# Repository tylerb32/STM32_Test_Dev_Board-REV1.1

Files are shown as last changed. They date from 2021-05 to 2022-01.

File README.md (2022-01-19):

# STM32_Test_Dev_Board-REV1.1
*Currently a work in progress<br/>
The purpose of this project is to gain experience with embedded system design, electronics and PCB design, and firmware/real-time software development in FreeRTOS.<br/>
Status: PCBs assembled (Investigating accelerometer hardware implementation).

Changes from REV 1:
- Changed component selection for MCU, crystal oscillator, and accelerometer due to availability and cost constraints
- Added switches for user input
- Improved positioning of LCD headers and ensured the screen won't block any other headers or connectors when plugged in
- Changed micro USB footprint
- Routed CBUS pins from UART-USB bridge and interrupt pins from the accelerometer to the MCU instead of external headers
- Routed remaining pins including LPUART to external headers

PCB 3D View
PCB Routing

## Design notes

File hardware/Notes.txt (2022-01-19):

Possible Improvements for Next Revision:
- Power LED
	- Nice to see if board is getting powered
- Test points
- Don't underestimate flash memory requirements

Testing:
	- Shuts off after 18 seconds when plugged into usb power pack
		* Does not occur when plugged into computer
		- Could be a result of USB suspend mode?
		- May need to program ftdi chip for usb charger use

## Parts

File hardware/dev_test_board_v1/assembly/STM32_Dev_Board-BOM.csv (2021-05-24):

Comment | Designator | Footprint | LCSC
10n | C1 | Capacitor_SMD:C_0603_1608Metric | C57112
1u | C11 | Capacitor_SMD:C_0402_1005Metric | C52923
6p | C13,C14 | Capacitor_SMD:C_0402_1005Metric | C30274
10u | C7,C15 | Capacitor_SMD:C_0402_1005Metric | C15525
4.7u | C2 | Capacitor_SMD:CP_Elec_4x5.4
100n | C3,C4,C8,C9,C10,C12,C16,C17 | Capacitor_SMD:C_0402_1005Metric | C1525
47p | C5,C6 | Capacitor_SMD:C_0603_1608Metric | C1671
YELLOW | D2 | LED_SMD:LED_0603_1608Metric | C72038
GREEN | D3 | LED_SMD:LED_0603_1608Metric | C72043
RED | D4 | LED_SMD:LED_0603_1608Metric | C2286
BLUE | D5 | LED_SMD:LED_0603_1608Metric | C72041
600R @ 100MHz | FB1 | Inductor_SMD:L_0805_2012Metric | C1017
MountingHole_Pad | H1,H2,H3,H4 | MountingHole:MountingHole_2.7mm_M2.5_Pad_Via
USB_B_Micro | J1 | tyjba_footprints:UBS_Micro-B_Citzends_Aliexpress
Conn_SWD | J2 | Connector_PinHeader_1.27mm:PinHeader_2x05_P1.27mm_Vertical
Conn_LCD | J3 | Connector_PinSocket_2.54mm:PinSocket_1x08_P2.54mm_Vertical
Conn_GP | J4 | Connector_PinHeader_2.54mm:PinHeader_1x12_P2.54mm_Vertical
27n | L1 | Inductor_SMD:L_0603_1608Metric | C12100
22R | R10 | Resistor_SMD:R_0402_1005Metric | C25092
1k | R11,R12,R13 | Resistor_SMD:R_0402_1005Metric | C11702
27R | R1,R2 | Resistor_SMD:R_0603_1608Metric | C25190
270R | R3,R4 | Resistor_SMD:R_0603_1608Metric | C22966
10k | R5 | Resistor_SMD:R_0402_1005Metric | C25744
1k | R6,R7 | Resistor_SMD:R_0603_1608Metric | C21190
4R7 | R8,R9 | Resistor_SMD:R_0402_1005Metric | C25900
SW_SPDT | SW1 | tyjba_footprints:SW_Unknown_SPDT_Straight
SW_PUSH | SW2,SW3,SW4 | Button_Switch_SMD:SW_Push_1P1T_NO_6x6mm_H9.5mm
STM32L031C4Tx | U1 | Package_QFP:LQFP-48_7x7mm_P0.5mm
FT230XS | U2 | Package_SO:SSOP-16_3.9x4.9mm_P0.635mm
LIS2HH12 | U3 | Package_LGA:LGA-12_2x2mm_P0.5mm
8MHz | Y1 | tyjba_footprints:Crystal_NX8045GB

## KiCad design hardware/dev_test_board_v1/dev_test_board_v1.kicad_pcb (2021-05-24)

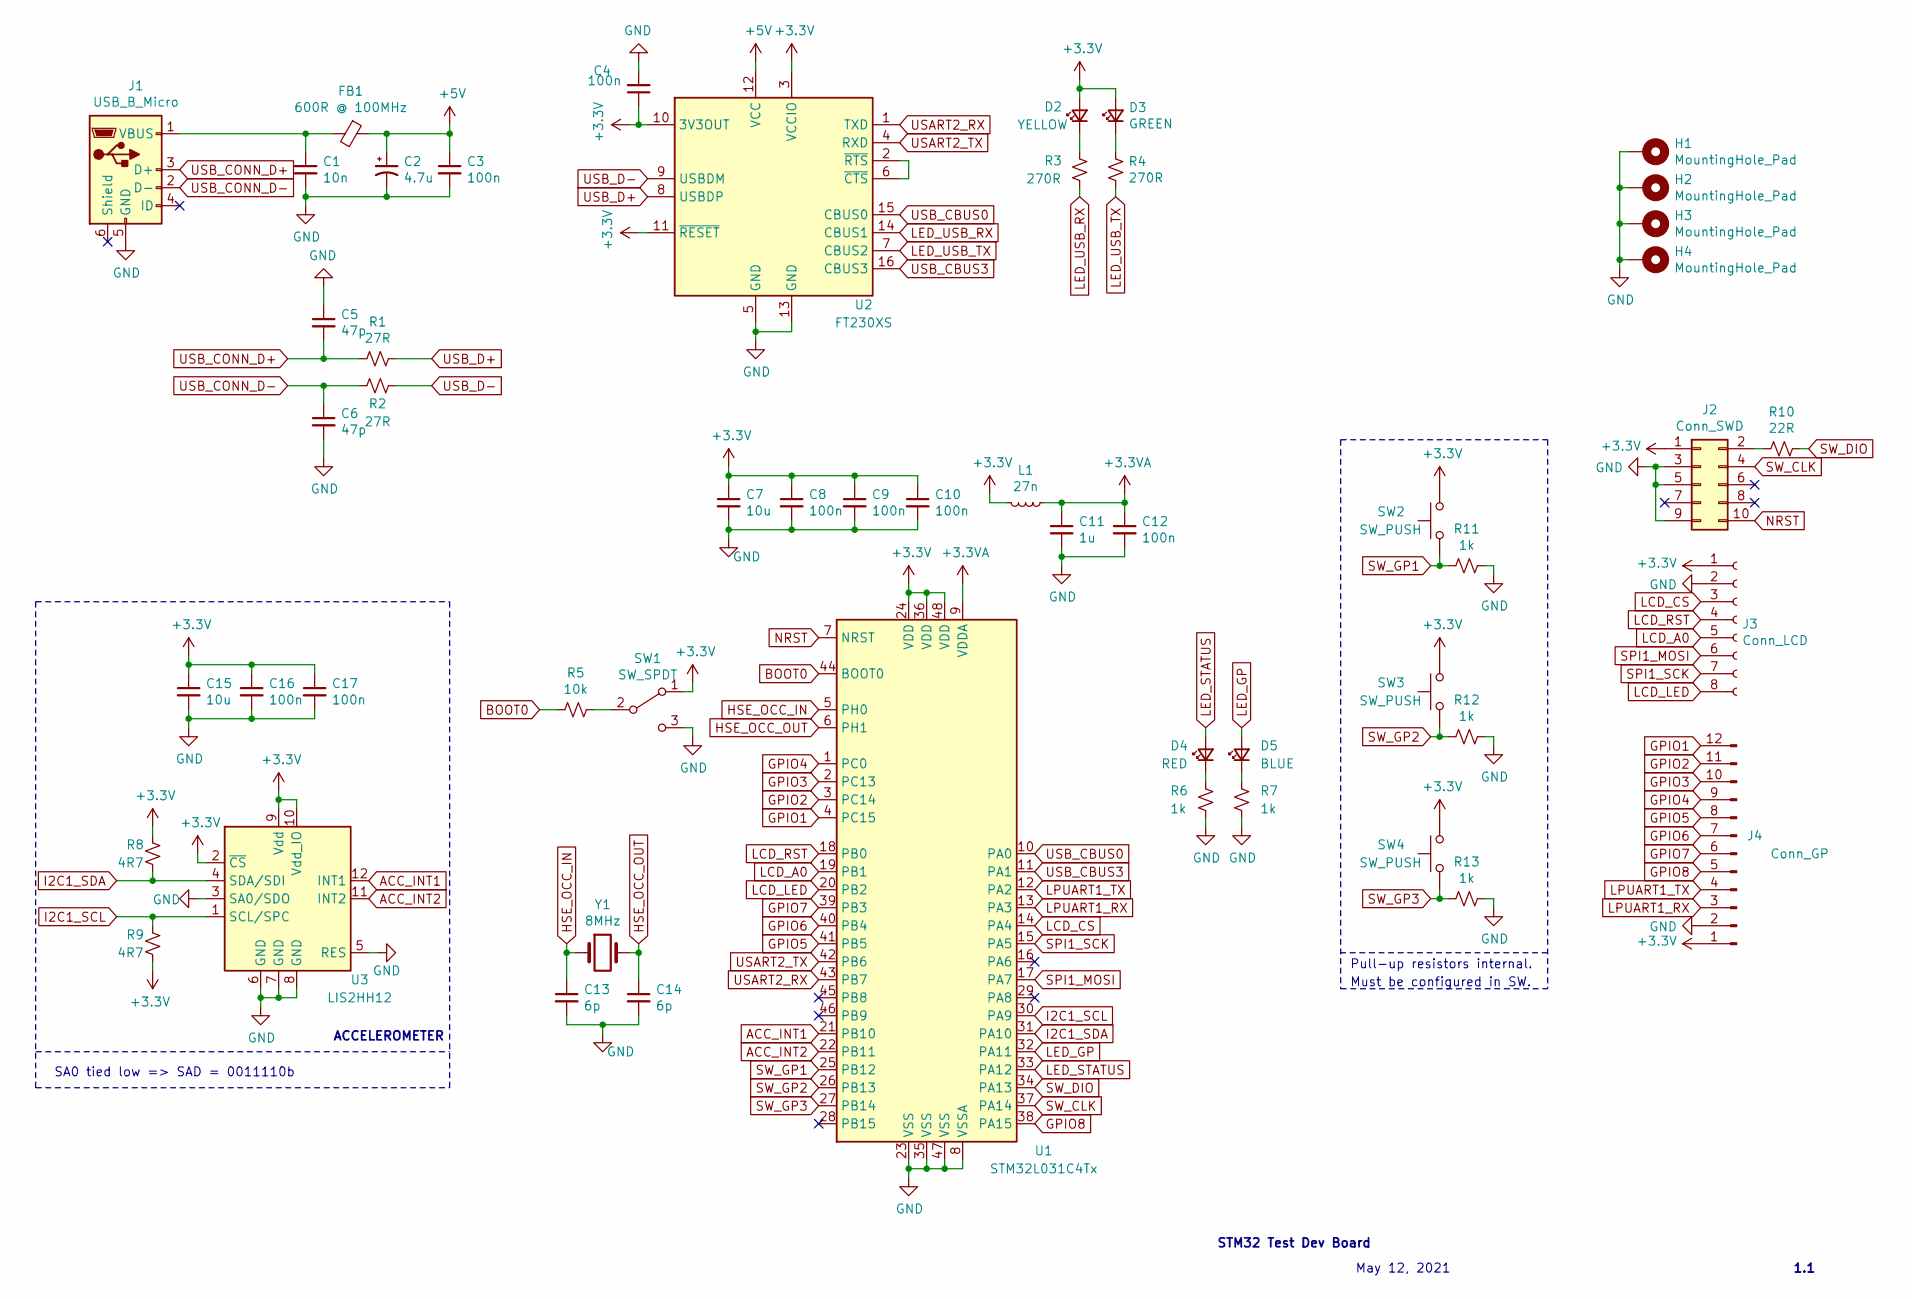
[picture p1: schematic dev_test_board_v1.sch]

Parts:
C1: 10n; C_0603_1608Metric; LCSC Part # C57112
C2: 4.7u; CP_Elec_4x5.4
C3, C4, C8, C9, C10, C12, C16, C17: 100n; C_0402_1005Metric; LCSC Part # C1525
C5, C6: 47p; C_0603_1608Metric; LCSC Part # C1671
C7, C15: 10u; C_0402_1005Metric; LCSC Part # C15525
C11: 1u; C_0402_1005Metric; LCSC Part # C52923
C13, C14: 6p; C_0402_1005Metric; LCSC Part # C30274
D2: YELLOW; LED_0603_1608Metric; LCSC Part # C72038
D3: GREEN; LED_0603_1608Metric; LCSC Part # C72043
D4: RED; LED_0603_1608Metric; LCSC Part # C2286
D5: BLUE; LED_0603_1608Metric; LCSC Part # C72041
FB1: 600R @ 100MHz; L_0805_2012Metric; LCSC Part # C1017
H1, H2, H3, H4: MountingHole_Pad; MountingHole_2.7mm_M2.5_Pad_Via
J1: USB_B_Micro; UBS_Micro-B_Citzends_Aliexpress
J2: Conn_SWD; PinHeader_2x05_P1.27mm_Vertical
J3: Conn_LCD; PinSocket_1x08_P2.54mm_Vertical
J4: Conn_GP; PinHeader_1x12_P2.54mm_Vertical
L1: 27n; L_0603_1608Metric; LCSC Part # C12100
R1, R2: 27R; R_0603_1608Metric; LCSC Part # C25190
R3, R4: 270R; R_0603_1608Metric; LCSC Part # C22966
R5: 10k; R_0402_1005Metric; LCSC Part # C25744
R6, R7: 1k; R_0603_1608Metric; LCSC Part # C21190
R8, R9: 4R7; R_0402_1005Metric; LCSC Part # C25900
R10: 22R; R_0402_1005Metric; LCSC Part # C25092
R11, R12, R13: 1k; R_0402_1005Metric; LCSC Part # C11702
SW1: SW_SPDT; SW_Unknown_SPDT_Straight
SW2, SW3, SW4: SW_PUSH; SW_Push_1P1T_NO_6x6mm_H9.5mm
U1: STM32L031C4Tx; LQFP-48_7x7mm_P0.5mm
U2: FT230XS; SSOP-16_3.9x4.9mm_P0.635mm
U3: LIS2HH12; LGA-12_2x2mm_P0.5mm
Y1: 8MHz; Crystal_NX8045GB

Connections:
+3.3VA: C11.1, C12.1, L1.1, U1.9 (VDDA)
+3V3: C4.1, C7.1, C8.1, C9.1, C10.1, C15.1, C16.1, C17.1, D2.2 (A), D3.2 (A), J2.1, J3.1, J4.1, L1.2, R8.2, R9.1, SW1.1 (A), SW2.2, SW3.2, SW4.2, U1.24 (VDD), U1.36 (VDD), U1.48 (VDD), U2.3 (VCCIO), U2.10 (3V3OUT), U2.11 (~RESET), U3.2 (~CS), U3.9 (Vdd), U3.10 (Vdd_IO)
+5V: C2.1, C3.1, FB1.1, U2.12 (VCC)
ACC_INT1: U1.21 (PB10), U3.12 (INT1)
ACC_INT2: U1.22 (PB11), U3.11 (INT2)
BOOT0: R5.2, U1.44 (BOOT0)
GND: C1.2, C2.2, C3.2, C4.2, C5.1, C6.2, C7.2, C8.2, C9.2, C10.2, C11.2, C12.2, C13.2, C14.2, C15.2, C16.2, C17.2, H1.1, H2.1, H3.1, H4.1, J1.5 (GND), J2.3, J2.5, J2.9, J3.2, J4.2, R6.2, R7.2, R11.1, R12.1, R13.1, SW1.3 (C), U1.8 (VSSA), U1.23 (VSS), U1.35 (VSS), U1.47 (VSS), U2.5 (GND), U2.13 (GND), U3.3 (SA0/SDO), U3.5 (RES), U3.6 (GND), U3.7 (GND), U3.8 (GND)
GPIO1: J4.12, U1.4 (PC15)
GPIO2: J4.11, U1.3 (PC14)
GPIO3: J4.10, U1.2 (PC13)
GPIO4: J4.9, U1.1 (PC0)
GPIO5: J4.8, U1.41 (PB5)
GPIO6: J4.7, U1.40 (PB4)
GPIO7: J4.6, U1.39 (PB3)
GPIO8: J4.5, U1.38 (PA15)
HSE_OCC_IN: C13.1, U1.5 (PH0), Y1.1
HSE_OCC_OUT: C14.1, U1.6 (PH1), Y1.2
I2C1_SCL: R9.2, U1.30 (PA9), U3.1 (SCL/SPC)
I2C1_SDA: R8.1, U1.31 (PA10), U3.4 (SDA/SDI)
LCD_A0: J3.5, U1.19 (PB1)
LCD_CS: J3.3, U1.14 (PA4)
LCD_LED: J3.8, U1.20 (PB2)
LCD_RST: J3.4, U1.18 (PB0)
LED_GP: D5.2 (A), U1.32 (PA11)
LED_STATUS: D4.2 (A), U1.33 (PA12)
LED_USB_RX: R3.2, U2.14 (CBUS1)
LED_USB_TX: R4.2, U2.7 (CBUS2)
LPUART1_RX: J4.3, U1.13 (PA3)
LPUART1_TX: J4.4, U1.12 (PA2)
NRST: J2.10, U1.7 (NRST)
unnamed: C1.1, FB1.2, J1.1 (VBUS)
unnamed: D2.1 (K), R3.1
unnamed: D3.1 (K), R4.1
unnamed: D4.1 (K), R6.1
unnamed: D5.1 (K), R7.1
unnamed: J2.2, R10.2
unnamed: R5.1, SW1.2 (B)
unnamed: U2.2 (~RTS), U2.6 (~CTS)
SPI1_MOSI: J3.6, U1.17 (PA7)
SPI1_SCK: J3.7, U1.15 (PA5)
SW_CLK: J2.4, U1.37 (PA14)
SW_DIO: R10.1, U1.34 (PA13)
SW_GP1: R11.2, SW2.1, U1.25 (PB12)
SW_GP2: R12.2, SW3.1, U1.26 (PB13)
SW_GP3: R13.2, SW4.1, U1.27 (PB14)
USART2_RX: U1.43 (PB7), U2.1 (TXD)
USART2_TX: U1.42 (PB6), U2.4 (RXD)
USB_CBUS0: U1.10 (PA0), U2.15 (CBUS0)
USB_CBUS3: U1.11 (PA1), U2.16 (CBUS3)
USB_CONN_D+: C5.2, J1.3 (D+), R1.2
USB_CONN_D-: C6.1, J1.2 (D-), R2.2
USB_D+: R1.1, U2.8 (USBDP)
USB_D-: R2.1, U2.9 (USBDM)

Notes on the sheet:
May 12, 2021
STM32 Test Dev Board
1.1
SA0 tied low => SAD = 0011110b
ACCELEROMETER
Pull-up resistors internal.
Must be configured in SW.

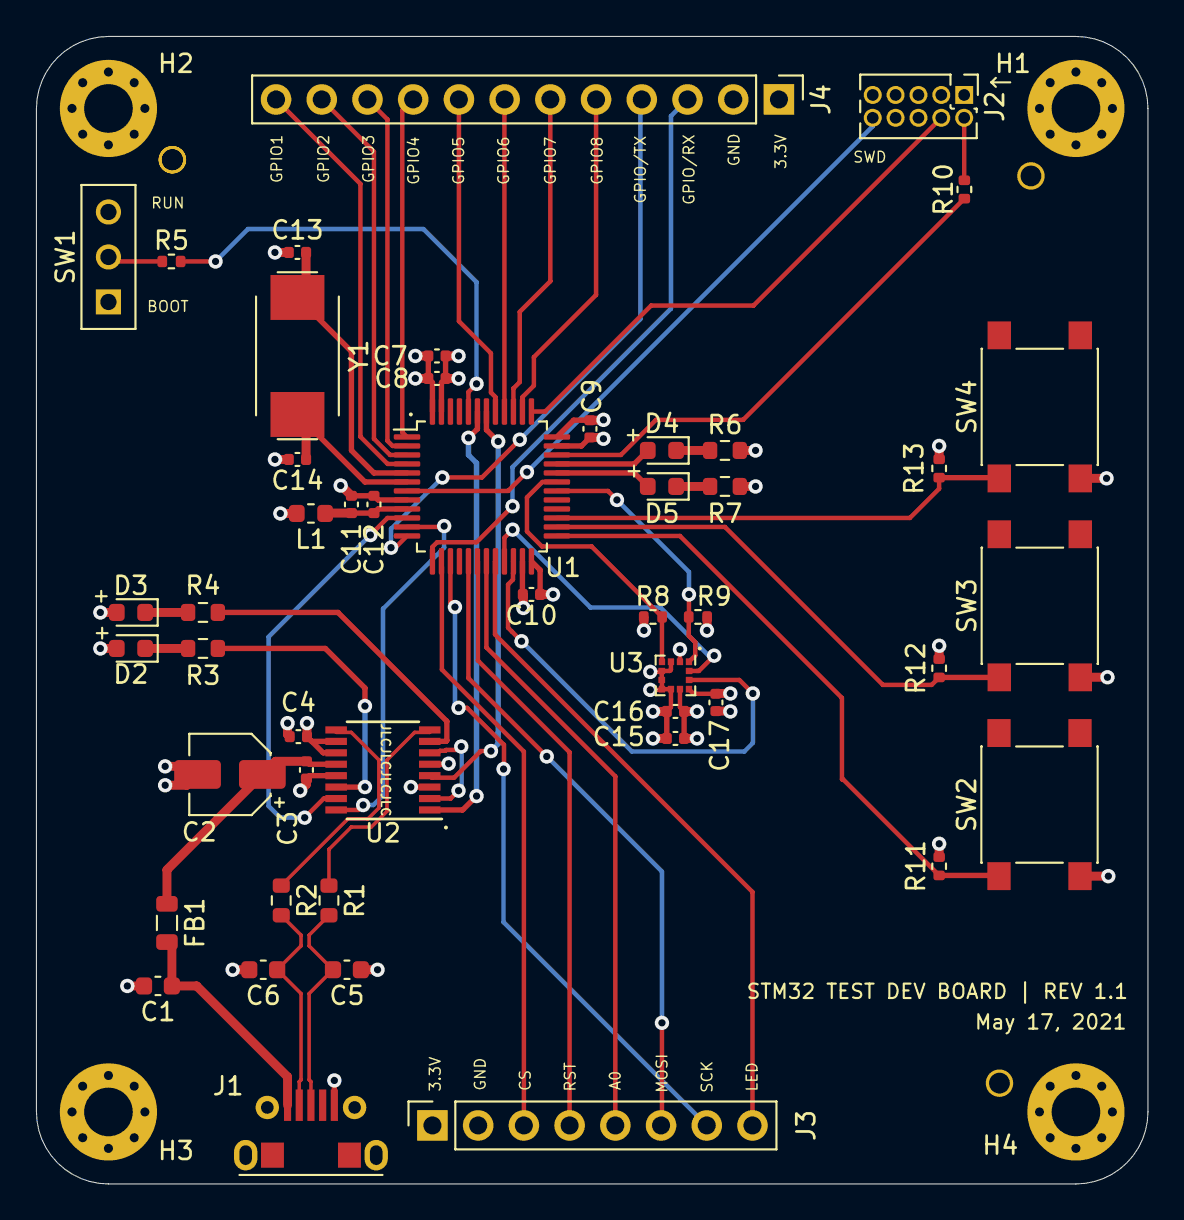
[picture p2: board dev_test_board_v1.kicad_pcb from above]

Board: 4 copper layers, 61.8 x 63.8 mm, 52 parts (0 on the bottom side), 53 nets.

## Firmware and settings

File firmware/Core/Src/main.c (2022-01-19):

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
/* Includes ------------------------------------------------------------------*/
#include "main.h"

/* USER CODE BEGIN Includes */
#include "LIS2HH12.h"
/* USER CODE END Includes */

I2C_HandleTypeDef hi2c1;

SPI_HandleTypeDef hspi1;

UART_HandleTypeDef huart2;

/* USER CODE BEGIN PV */
LIS2HH12 acc;
uint8_t acc_data_ready;
/* USER CODE END PV */

void SystemClock_Config(void);
static void MX_GPIO_Init(void);
static void MX_I2C1_Init(void);
static void MX_SPI1_Init(void);
static void MX_USART2_UART_Init(void);
/* USER CODE BEGIN 0 */
void HAL_GPIO_EXTI_Callback(uint16_t GPIO_Pin)
{
	if (GPIO_Pin == GPIO_PIN_10) {
		acc_data_ready = 1;
	}
}
/* USER CODE END 0 */

/**
  * @brief  The application entry point.
  * @retval int
  */
int main(void)
{
  /* MCU Configuration--------------------------------------------------------*/

  /* Reset of all peripherals, Initializes the Flash interface and the Systick. */
  HAL_Init();

  /* Configure the system clock */
  SystemClock_Config();

  /* Initialize all configured peripherals */
  MX_GPIO_Init();
  MX_I2C1_Init();
  MX_SPI1_Init();
  MX_USART2_UART_Init();
  /* USER CODE BEGIN 2 */
  // TODO: Context switch code

  // Initialize accelerometer
  LIS2HH12_Initialize(&acc, &hi2c1);

  // Set priorities
  NVIC_SetPriority(PendSV_IRQn, 0xFF); // Lowest priority
  NVIC_SetPriority(SysTick_IRQn, 0x00); // Highest priority



  uint32_t ret_val = SysTick_Config(SystemCoreClock);

  // Pull CBUS3 low for Keep_Awake# setting on FTDI chip
  HAL_GPIO_WritePin(GPIOA, GPIO_PIN_1, GPIO_PIN_RESET);
  /* USER CODE END 2 */

  /* Infinite loop */
  /* USER CODE BEGIN WHILE */
  acc_data_ready = 0;
  while (1)
  {
	  // Read accelerometer data
	  if (acc_data_ready) {
		  LIS2HH12_ReadOrientation(&acc);
		  acc_data_ready = 0;
	  }

	  // Poll button 1 press and power blue LED accordingly
	  if (HAL_GPIO_ReadPin(GPIOB, GPIO_PIN_14)) {
		  HAL_GPIO_TogglePin(GPIOA, GPIO_PIN_12);
	  }

	  // Transmit test msg over UART on button 2 press
	  if (HAL_GPIO_ReadPin(GPIOA, GPIO_PIN_1)) {
		  HAL_UART_Transmit(&huart2, "TESTING", 8, 100);
	  }
  }
  /* USER CODE END WHILE */
}

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


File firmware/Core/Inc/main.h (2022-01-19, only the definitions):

#define USB_CBUS3_Pin GPIO_PIN_1
#define USB_CBUS3_GPIO_Port GPIOA
#define LCD_CS_Pin GPIO_PIN_4
#define LCD_CS_GPIO_Port GPIOA
#define LCD_RST_Pin GPIO_PIN_0
#define LCD_RST_GPIO_Port GPIOB
#define LCD_A0_Pin GPIO_PIN_1
#define LCD_A0_GPIO_Port GPIOB
#define LCD_LED_Pin GPIO_PIN_2
#define LCD_LED_GPIO_Port GPIOB
#define ACC_INT1_EXT_Pin GPIO_PIN_10
#define ACC_INT1_EXT_GPIO_Port GPIOB
#define ACC_INT1_EXT_EXTI_IRQn EXTI4_15_IRQn
#define SW_GP1_Pin GPIO_PIN_12
#define SW_GP1_GPIO_Port GPIOB
#define SW_GP2_Pin GPIO_PIN_13
#define SW_GP2_GPIO_Port GPIOB
#define SW_GP3_Pin GPIO_PIN_14
#define SW_GP3_GPIO_Port GPIOB
#define LED_GP_Pin GPIO_PIN_11
#define LED_GP_GPIO_Port GPIOA
#define LED_STATUS_Pin GPIO_PIN_12
#define LED_STATUS_GPIO_Port GPIOA

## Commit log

2021-05-12 All needed pins assigned.
    [dev_test_board_v1.sch]
2021-05-13 Components labelled, HSE oscillator added.
    [dev_test_board_v1.sch]
2021-05-15 Started PCB layout.
    [dev_test_board_v1.kicad_pcb, dev_test_board_v1.sch]
2021-05-15 Draft layout complete.
    [dev_test_board_v1.kicad_pcb, dev_test_board_v1.sch]
2021-05-16 All signals routed.
    [dev_test_board_v1.kicad_pcb, dev_test_board_v1.sch]
2021-05-17 Removed HW debouncing for SW2-4, finished routing.
    [dev_test_board_v1.kicad_pcb, dev_test_board_v1.sch]
2021-05-18 Fixed via placement errors. Added silkscreen for annotations.
    [dev_test_board_v1.kicad_pcb]
2021-05-24 Routing cleaned up a bit and PCBs ordered.
    [STM32_Dev_Board-BOM.csv, STM32_Dev_Board-Positions.csv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]
2021-05-24 Fixed 3D models for switches.
    [dev_test_board_v1.kicad_pcb]
2022-01-19 I2C driver push - suspected hardware failure
    [LIS2HH12.c, STM32_Dev_Board-FW.ioc, main.c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]

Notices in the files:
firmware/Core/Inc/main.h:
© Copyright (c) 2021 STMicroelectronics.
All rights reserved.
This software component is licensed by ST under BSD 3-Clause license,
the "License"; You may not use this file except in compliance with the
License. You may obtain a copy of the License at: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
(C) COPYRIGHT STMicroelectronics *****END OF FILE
